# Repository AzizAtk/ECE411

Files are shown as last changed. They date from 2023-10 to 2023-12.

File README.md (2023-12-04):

# ECE411 Audio Visualizer

Team 5

Team Members: Abdulaziz Alateeqi, Meshal Almutairi, Gene Hu, Flynn Flynn

## Project Overview
This project is a dynamic audio visualizer that reacts to the audio input signal in real-time, by illuminating an LED panel in patterns and colors corresponding to the audio’s signal. This device will be a must-have gadget for tech enthusiasts to upgrade their listening space. By utilizing digital signal processing and Fast Fourier Transforms, audio signals are displayed visually as beautiful LED arrays. Just plug the device into a standard DC USB block and turn on the power switch and the device is ready to operate.

## System Architecture
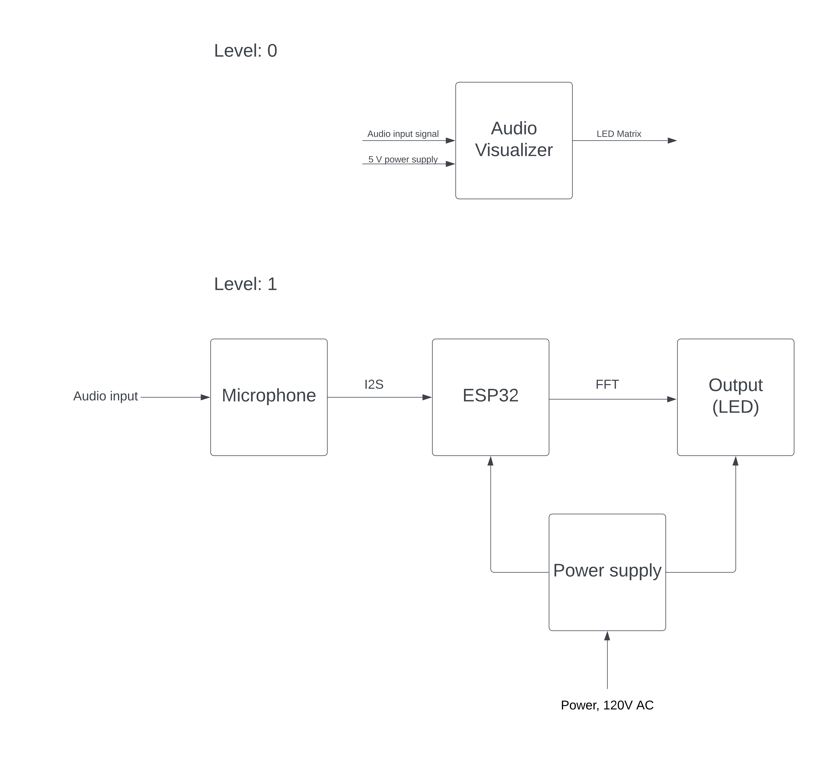
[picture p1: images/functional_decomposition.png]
func_decomp


## CAD Design
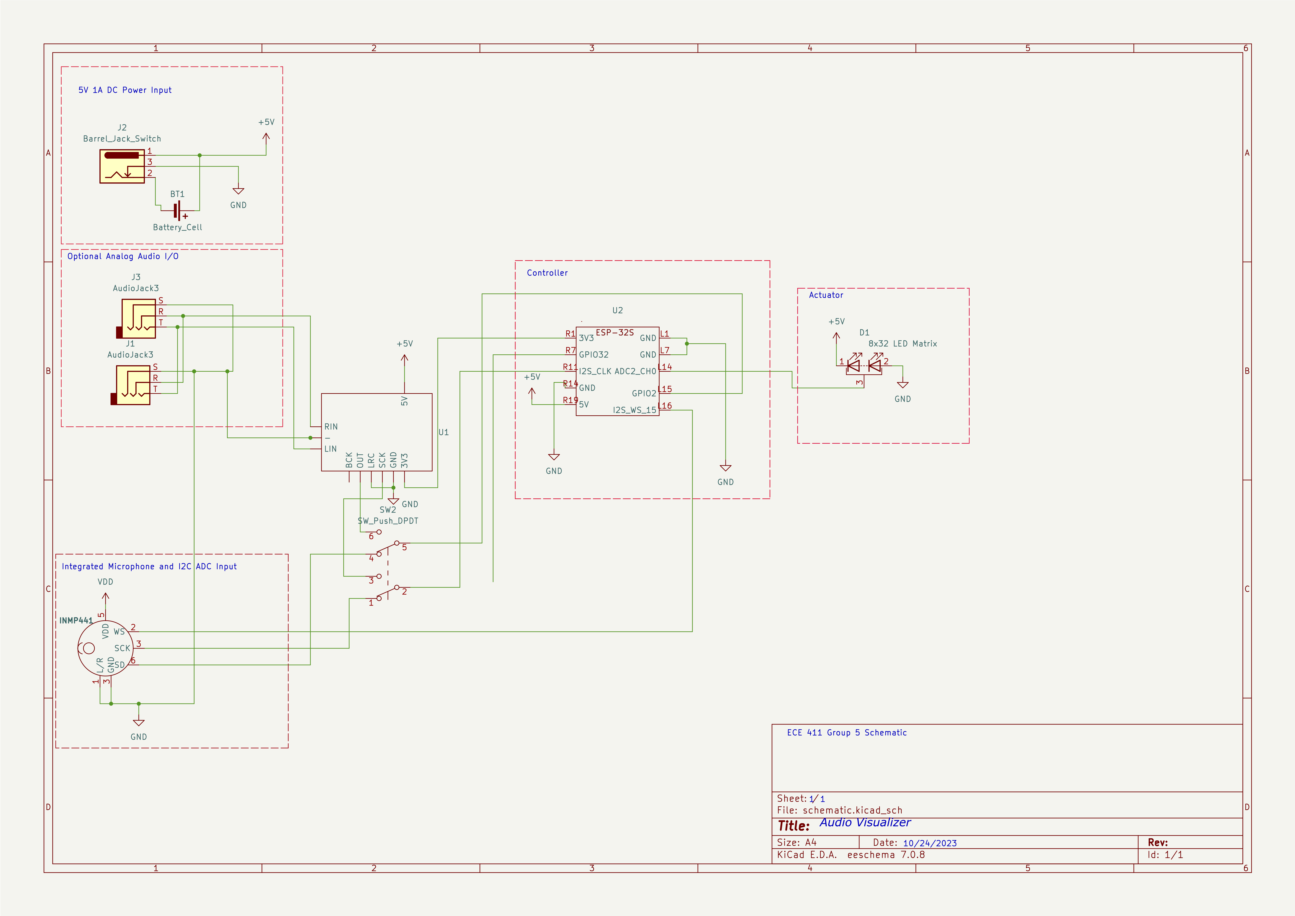
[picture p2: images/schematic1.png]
schematic1

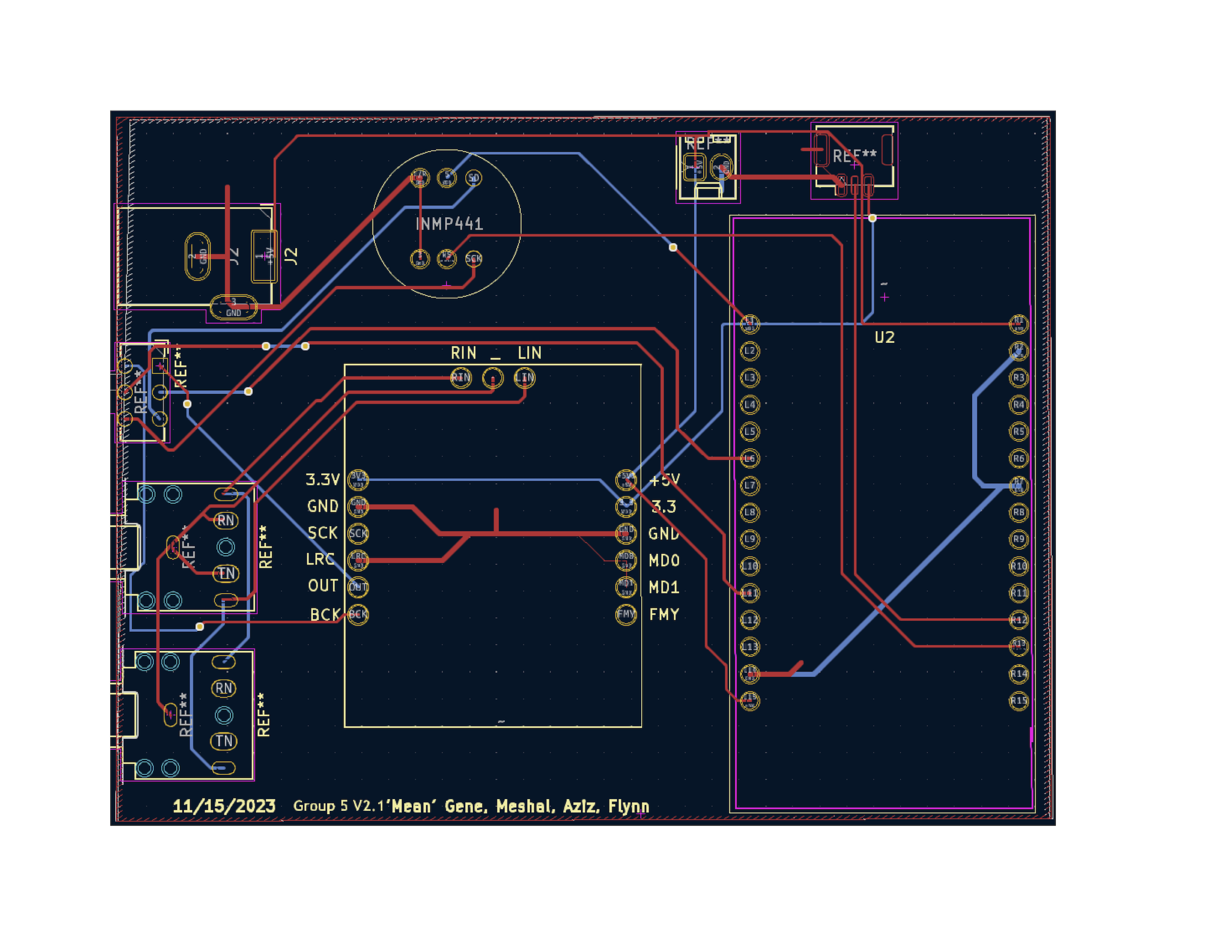
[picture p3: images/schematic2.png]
schematic2


## Software Design

### Audio
- The audio is sampled using I2S.

### FFT
- The FFT is implemented using the ArduinoFFT library.
- The FFT is used to convert the audio signal from the time domain to the frequency domain.
- The FFT is used to determine the amplitude of each frequency.

### LED Matrix
- The LED matrix is controlled using the FastLED and LEDMatrix libraries.
- The LED matrix is used to display the amplitude of each frequency as a bar graph.

## Prototype
<details>
  <summary>Click to expand prototype</summary>

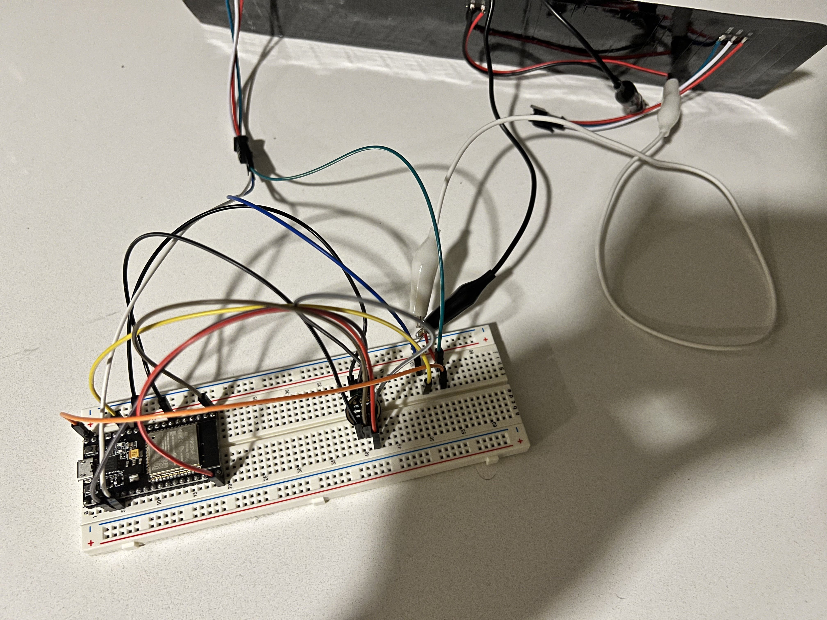
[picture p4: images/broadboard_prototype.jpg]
prototype
  
</details>

## Design Specification

### Power Requirements
The project will require dedicated 5V 3A power that will need a dedicated AC wall adapter.
- A 2.1mm barrel jack will be mounted directly to the board.
- A standard USB to 2.1mm cable will attach to a Samsung USB block.
- The 5V will attach to the board via a trace (larger duty).

### Sensors
- The first input will be switchable between a 3.5mm TRS line level input.
  - This will run directly to Ain and Din on the ESP32.
  - The input TRS 3.5mm jack will be wired directly to a second TRS that routes audio to an external powered speaker.
- INMP441 microphone module.
- Inputs will be switchable with only one operating at a time.

### Actuators
- The output of the device will be an 8x32 LED matrix.
- The display will be a two-dimensional spectrogram.
  - The X-axis is the different frequencies.
  - The Y-axis is amplitude in volts.
- This will be done by individually addressing each light using each frequency as a logic parameter and the voltage reading to determine how many lights from that column illuminate.
- This will be on a purchased breakout board with power, ground, and address/clk line being connected to PCB via a 4-pin ribbon cable.

### Processing
- All processing will be done on an ESP32 microcontroller.
- Arduino IDE will be used as the programming environment.
- The controller will take in digital audio signals and process them into the frequency domain as a Fourier Transform.
- Different frequencies will be made into control loops for the program output.
- ESP32 will be mounted to the PCB via headers and sockets so the microcontroller can be removed for programming.

## Requirements

### Performance
- Must continuously visualize the input sound until switched off.
- Must be displaying accurate information (i.e., high LED bar if the frequency is overwhelming).
- Must be able to use a microphone to process the audio of surroundings.
- Should be able to take in sound through an audio jack.
  - Should have a speaker.

### User Experience
- Must be portable.
- Must be wall-powered through the adapter.
- Should be simple to use (plug and go).
- May use batteries.
  - May be rechargeable.

### Safety
- Must not overheat or be at risk of burning out LEDs.
- May be able to withstand being dropped lightly (No shattering?).

### Miscellaneous
- Should be able to switch the audio rails for input/output instead of having two separate lines.

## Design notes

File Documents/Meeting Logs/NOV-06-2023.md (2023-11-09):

### Meeting Summary:
   1. Short meeting to create a BOM
      - Missing some part details that needs to be filled
   2. Worked on functional decomposition

### For Next Meeting:
    1. Must discuss how to split the frequency bands in higher detail
    2. Finish up BOM and functional decomposition before Thursday

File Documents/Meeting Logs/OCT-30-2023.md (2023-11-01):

### Meeting Summary:
   1. Created a comprehensive project schedule.

### For Next Meeting:
1. Revise schematic
2. Make Bill of Materials (BOM)
3. Draw top-level block diagrams (functional decomposition)
4. Work on sensors and actuators software

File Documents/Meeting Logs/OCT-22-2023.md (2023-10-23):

### Meeting Summary:
   1. Completed "HW Wk 05 - Make a decision!"
   2. The LED matrix and microphone has been received
   3. Flynn started working on a preliminary schematic
   4. Started keeping track of a bill of matrials
   5. Ordered three ESP32
   6. Decided on roles
      -   Flynn: Hardware
      -   Meshal: Head software developer
      -   Gene: Junior developer 
      -   Aziz: Junior developer 

### For Next Meeting:
1. Complete the preliminary schematic

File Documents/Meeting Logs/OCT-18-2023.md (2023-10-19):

### Meeting Summary:
   1. Completed PDS

### Parts list:
#### Parts we have:
- ESP32
- Switch
- Power Cable
##### Parts to order:
- [INMP441 Microphone](https://www.amazon.com/AITRIP-Omnidirectional-Microphone-Precision-Interface/dp/B092HWW4RS/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,aps,157)
- Headphone jack input module
- [8x32 LED Panel](https://www.amazon.com/dp/B088BTXHRG/?th=1)
- Speaker
- Diffusive filter panel

### For Next Meeting:
1. Order parts
2. Work on HW5
3. Look into 3D printing enclosure

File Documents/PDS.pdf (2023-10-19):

# Product Description Specification

### October 19, 2023

### ECE 411 Dr. Andrew Greenberg

### TEAM 5

Abdulaziz Alateeqi, | Meshal Almutairi
Flynn Flynn, | Gene Hu

## Executive Summary

The audio visualizer takes an audio input from the user and displays a visual representation of the processed audio signal on an LED panel. This device will be a must have gadget for tech enthusiasts to upgrade their listening space. By utilizing digital signal processing and fast fourier transforms, audio signals are displayed visually as beautiful LED arrays. Just plug the device into a standard DC USB block and turn on the power switch and the device is ready to operate.

## Market Analysis

Our audio visualizer is tailored for musicians and music listeners seeking to enhance their listening experience with visual flair. In the current market, the main competitor is software-based solutions that offer real-time music visualization on screens. Our product distinguishes itself by providing a seamlessly integrated audio-visual experience. Considering the cost of components and the product’s unique appeal, we expect the price to be around $40.

## Requirements

### Performance

1. Must continuously visualize the input sound until switched off
2. Must be displaying accurate information (i.e. high LED bar if the frequency is overwhelming)
3. Must be able to use a microphone to process audio of surrounding
4. Should be able to take in sound through an audio jack
a. Should have a speaker

### User Experience

1. Must be portable
2. Must be wall powered through adapter
3. Should be simple to use (plug and go)
4. May use batteries
a. May be rechargeable

1

### Safety

1. Must not overheat or be at risk of burning out LEDs
2. May be able to withstand being dropped lightly (No shattering?)

### Miscellaneous

1. Should be able to switch the audio rails for input/output instead of having two separate lines

## System Architecture

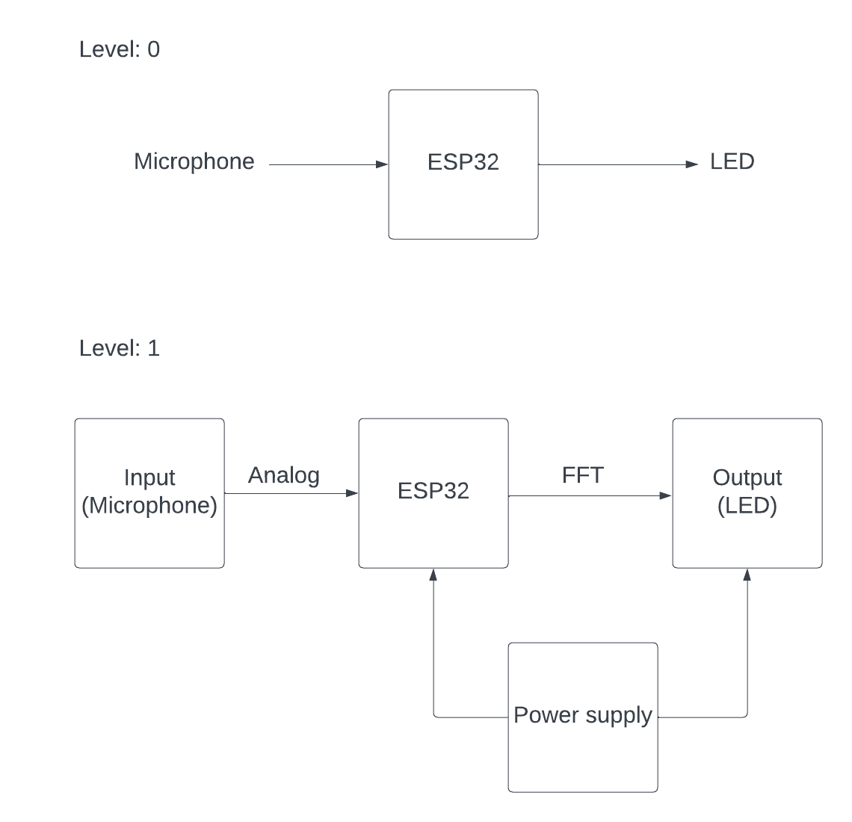
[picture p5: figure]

## Design Specification

### Power requirements

The project will require dedicated 5v 3A power that will need a dedicated AC wall adapter.

- A 2.1mm barrel jack will be mounted directly to the board

2

- A standard USB to 2.1mm cable will attach to a samsung USB block
- The 5v in will attach to the board via a trace (larger duty)

### Sensors

- First input will be switchable between a 3.5mm TRS line level input
- This will run directly to Ain and Din on the ESP32
- The input TRS 3.5mm jack will be wired directly to a second TRS that routes audio to an external powered speaker.
- INMP441 microphone module
- Inputs will be switchable with only one operating at a time

### Actuators

- The output of the device will be an 8x32 LED matrix.
- The display will be a two dimensional spectrogram.
- X-axis is the different frequencies.
- Y-axis is amplitude in volts.
- This will be done by individually addressing each light using each frequency as a logic parameter and the voltage reading to determine how many lights from that column illuminate.
- This will be on a purchased breakout board with pwr, gnd and address/clk line being connected to PCB via a 4 pin ribbon cable.

### Processing

- All processing will be done on a ESP32 microcontroller.
- Arduino IDE will be used as the programming environment.
- The controller will take in digital audio signals and process them into the frequency domain as a Fourier Transform.
- Different frequencies will be made into control loops for the program output.

3

- ESP32 will be mounted to the pcb via headers and sockets so the microcontroller can be removed for programming.

4

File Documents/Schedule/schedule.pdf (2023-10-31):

ece411 Project Schedule | Oct 30, 2023 http://

## Project manager

Project dates | Oct 30, 2023 - Dec 8, 2023
Completion | 0%
Tasks | 16
Resources | 4

Project schedule for ece411 team5's audio visualizer.

Name | Begin date | End date
Breadboard Prototype Create a breadboard prototype of the audio visualizer. Done by putting all the components together onto a BB and using wires on hand to connect the circuit. | 10/30/23 | 11/1/23

## Updated Schematic and Preliminary Layout

Your schematic should now be much closer to completion.

Your preliminary board layout should have all of your major components on it, including power supply, sensor, controller, and actuator. It should have a vaguely reasonable board outline. It doesn't have to be fully routed, or even halfway routed, but components should be grouped together, and components should be put in sane places.

And, of course, make sure this is checked in under version control!

Submit it in TWO WAYS:

Print a PDF of your schematic and board layout and upload it to Canvas. Enter a URL to your collaboration site to the folder where your schematic and layout files are checked in.

10/30/23 | 11/1/23

## Code Microphone

Interface microphone component with ESP32 and make it functional.

11/3/23 | 11/7/23

## Code LED Control

Interface 8x32 LED panel with ESP32 and be able to control it. Basic control being able to light up "bars" to represent the incoming frequencies.

11/3/23 | 11/7/23

## Code Frequency Analyzer

Code a frequency analyzer (FFS) onto the ESP32.

11/3/23 | 11/7/23

## Combine and Test Code

Combine the code from each component to get a working audio visualizer prototype.

11/8/23 | 11/12/23

## Debug and Fix

Debug the combined code and fix any errors.

11/13/23 | 11/17/23

## Bill of Materials

Final BOM filled here:
https://docs.google.com/spreadsheets/d/1jbas32DcEDZ59e13n7u7aIlfJYj-6RpcqCJsSKwKe8E/edit?usp=sharing

Make sure to upload to GitHub

11/4/23 | 11/5/23

## Rough Draft of CAD

The only things left are changes for out of stock components, changes from design reviews, changes for DFX, etc.!

And, of course, make sure this is checked in under version control!

Submit it in TWO WAYS:

Print a PDF of your schematic and board layout and upload it to Canvas. Enter a URL to your collaboration site to the folder where your schematic and layout files are checked in.

11/5/23 | 11/7/23

## Functional Decomposition

Draw a top-level (Level 0) block diagram of your practicum project showing all inputs and outputs.

Draw a Level 1 block diagram showing the principal components or modules of your project along with the interconnections between them. LABEL ALL INTERCONNECTIONS.

Consult the lecture slides for proper format for capturing the block diagram and describing inputs and outputs.

Post these to your collab site and upload a PDF to Canvas.

11/4/23 | 11/6/23

## Design Review

Have at least one other team design review your schematic and layout. Bonus points for more than one design review by more than one team. Be attentive! Take notes!

Submit which team(s) (use their team number) did your design review(s).

11/11/23 | 11/14/23
ece411 Project Schedule | Oct 30, 2023
Tasks | 2

Name | Begin date | End date
Final CAD After your design review, fix all of the critical issues, go through all the checklists again, and then declare it done! And of course, check it in to your versioning system! Submit it in TWO WAYS: Print a PDF of your schematic and board layout and upload it to Canvas. Enter a URL to your collaboration site to the folder where your schematic and layout files are checked i | 11/15/23 | 11/16/23

## Send Board to FAB

Must be sent between 12 p.m. Thursday and 10 a.m. Friday.

11/16/23 | 11/16/23

## Test Plan

Create a comprehensive hierarchical test plan for your practicum project. Consult the course lecture notes for guidelines. Submit at least three test plans (see optional testing template document).

Create detailed test case descriptions for two tests included in your test plan.

Your work will be graded on completeness, conformance to design documentation requirements as described in class, and quality and clarity of the individual test cases.

Post these to your team wiki and upload a single PDF file of them to Canvas.

11/23/23 | 11/27/23
Assemble Final Build | 11/28/23 | 11/28/23
Presentation 30 minutes, either Thursday or Friday | 12/7/23 | 12/7/23
Tasks | 3

Name | Default role
Gene Hu | developer
Flynn | developer
Meshal | developer
Aziz | developer

# Resources

# Gantt Chart

Name | Begin date | End date
Breadboard Prototype | 10/30/23 | 11/1/23
Updated Schematic and... | 10/30/23 | 11/1/23
Code Microphone | 11/3/23 | 11/7/23
Code LED Control | 11/3/23 | 11/7/23
Code Frequency Analyzer | 11/3/23 | 11/7/23
Combine and Test Code | 11/8/23 | 11/12/23
Debug and Fix | 11/13/23 | 11/17/23
Bill of Materials | 11/4/23 | 11/5/23
Rough Draft of CAD | 11/5/23 | 11/7/23
Functional Decomposition | 11/4/23 | 11/6/23
Design Review | 11/11/23 | 11/14/23
Final CAD | 11/15/23 | 11/16/23
Send Board to FAB | 11/16/23 | 11/16/23
Test Plan | 11/23/23 | 11/27/23
Assemble Final Build | 11/28/23 | 11/28/23
Presentation | 12/7/23 | 12/7/23
Oct'2023 | November 2023 | December 2023
30 | 31

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
9 | 10 | 11 | 12 | 13 | 14 | 15 | 16 | 17 | 18 | 19 | 20 | 21 | 22 | 23 | 24 | 25 | 26 | 27 | 28 | 29 | 30

1

2

3
4

Send Board to FAB

# Resources Chart

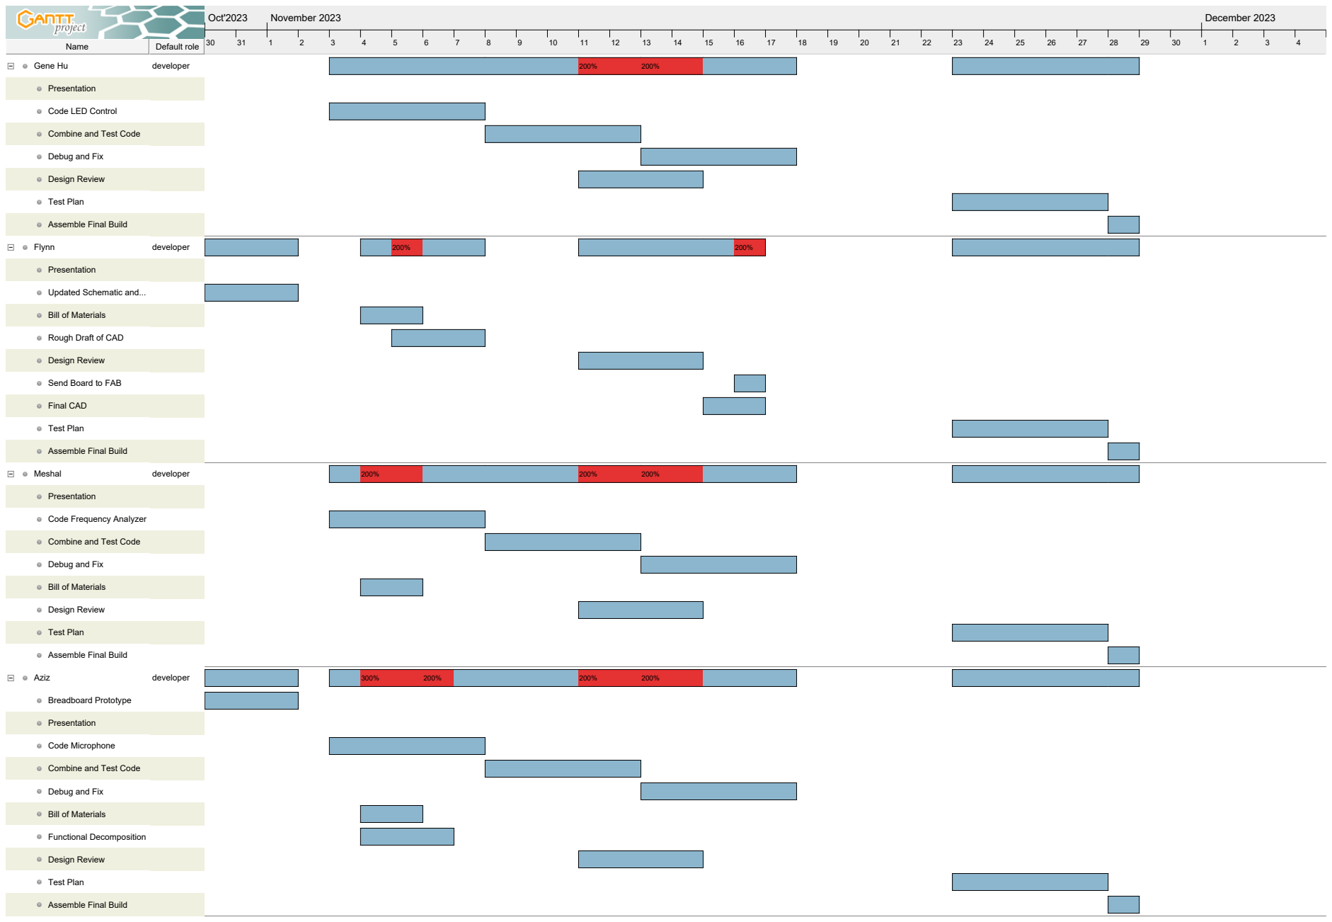
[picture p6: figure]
Name; Default role; Gene Hu; developer; Presentation; Code LED Control; Combine and Test Code; Debug and Fix; Design Review; Test Plan; Assemble Final Build; Flynn; Updated Schematic and...; Bill of Materials; Rough Draft of CAD; Send Board to FAB; Final CAD; Meshal; Code Frequency Analyzer; Aziz; Breadboard Prototype; Code Microphone; Functional Decomposition; Oct'2023; November 2023; December 2023

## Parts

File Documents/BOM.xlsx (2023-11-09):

Bill Of Materials for: Team 5
Last modified: 11/06/2023
PCB version: 0.1
BOM revision: 2 |  | P/NP | = Place/Not Place (components marked NP are not stuffed on the board)
Cnt | Part References | P/NP | Mfg | Mfg PN | Description | Dist | Dist Part Number | Cost Ea. | Cost Total
4 | C11, C17, C22, C23 | P | Yageo | CC0603KRX5R7BB105 | 1µF ±10% 16V Ceramic Capacitor X5R 0603 | Digi-Key | 311-1444-1-ND | $0.11 | $0.44
1 | D1 | P | BTF-LIGHTING | WS2812B ECO RGB | 8X32 programmable LED Matrix | Amazon | - | $18.99 | $18.99
5 | Mic1 | P | AITRIP | INMP441 | Omnidirectional Microphone Module | Amazon | - | $2.80 | $13.99
10 | J1 | NP | TRRS | 3.5mm Audio Jack Breakout Board | Connector_Audio:AudioJack3 | Amazon | - | $0.60 | $5.99
10 | J2 | P | DAYKIT | 12V Male+Female 2.1x5.5MM DC Power Jack | Connector:Barrel_Jack_Switch | Amazon | - | $0.80 | $7.99
1 | U1 | P | Texas Instruments | PCM1808PWR | CJMCU-1808 ADC converter | Digi-Key | 296-26307-6-ND | $1.81 | $1.81
3 | U2 | P | Espressif Systems | ESP32-DEVKITM-1 | ESP WROOM 32 microcontroller | Digi-Key | 1965-ESP32-DEVKITM-1-ND | $5.29 | $15.88
 |  |  |  |  |  |  |  | TOTAL: | $65.09
VERSION INFO
Rev | Date | Notes
0.1r1 | 2023-11-06 | Initial BOM. All parts chosen. Most are missing Dist Part Number.

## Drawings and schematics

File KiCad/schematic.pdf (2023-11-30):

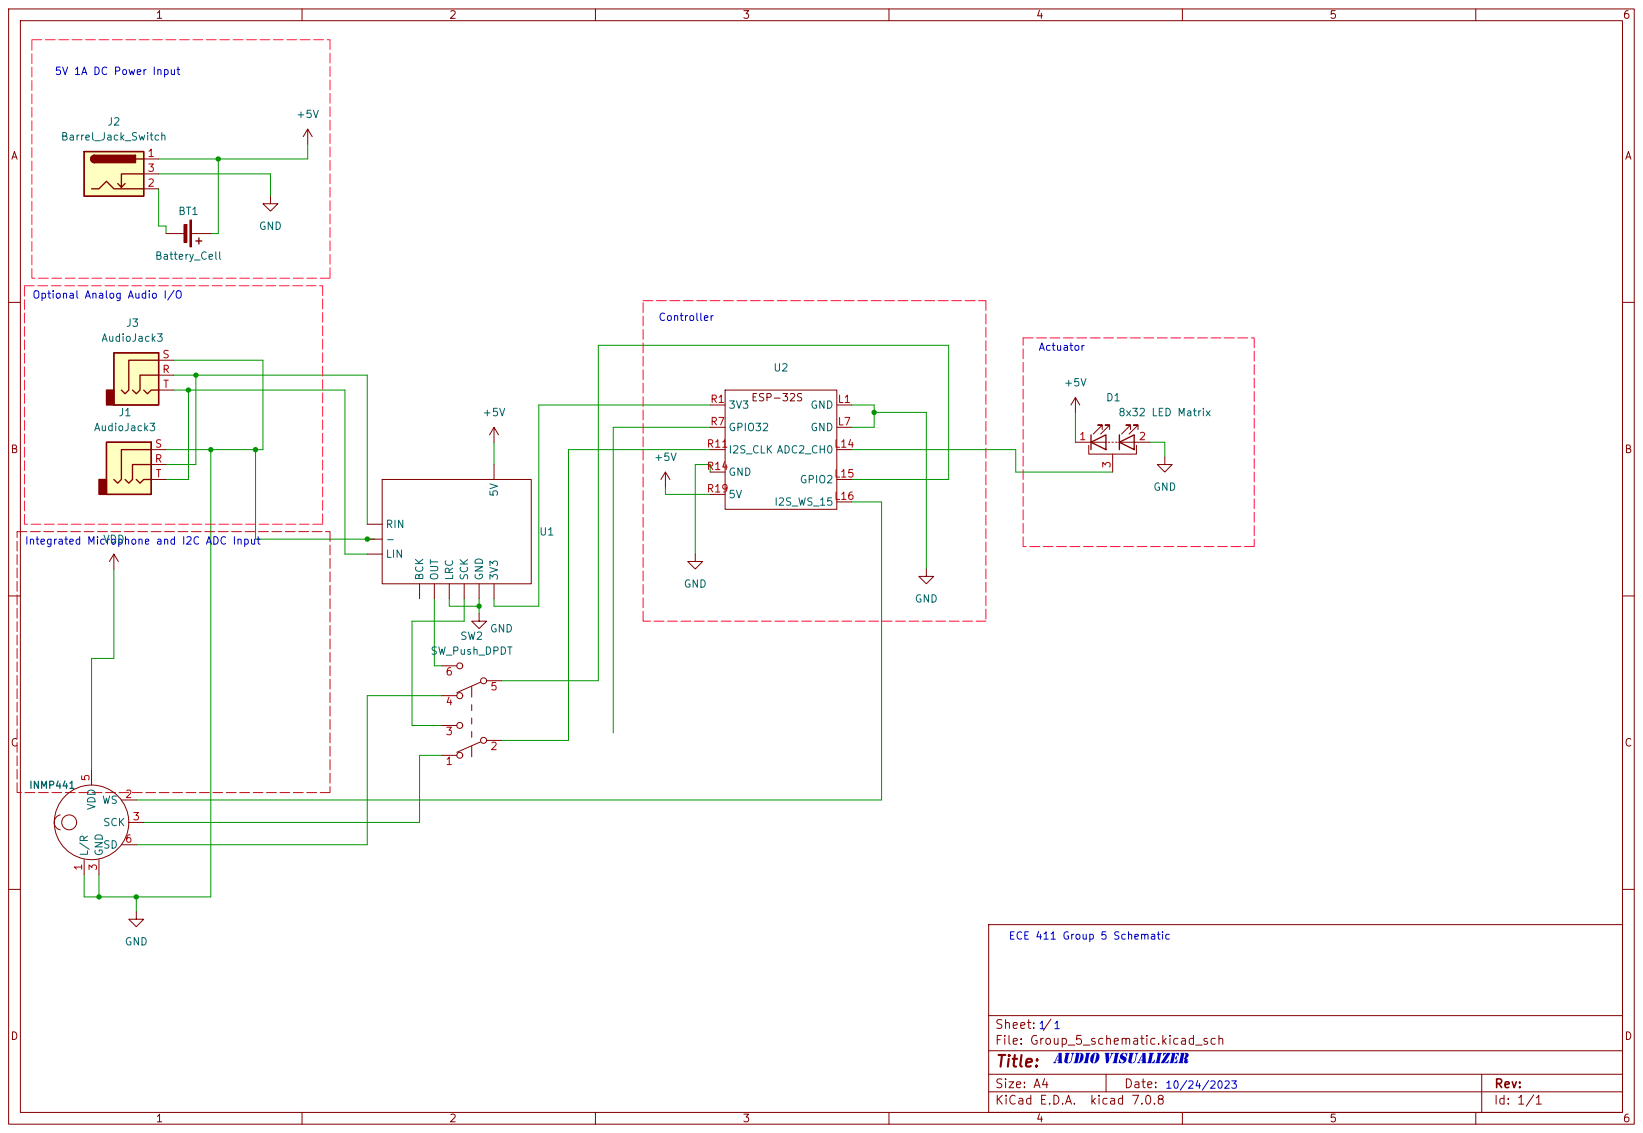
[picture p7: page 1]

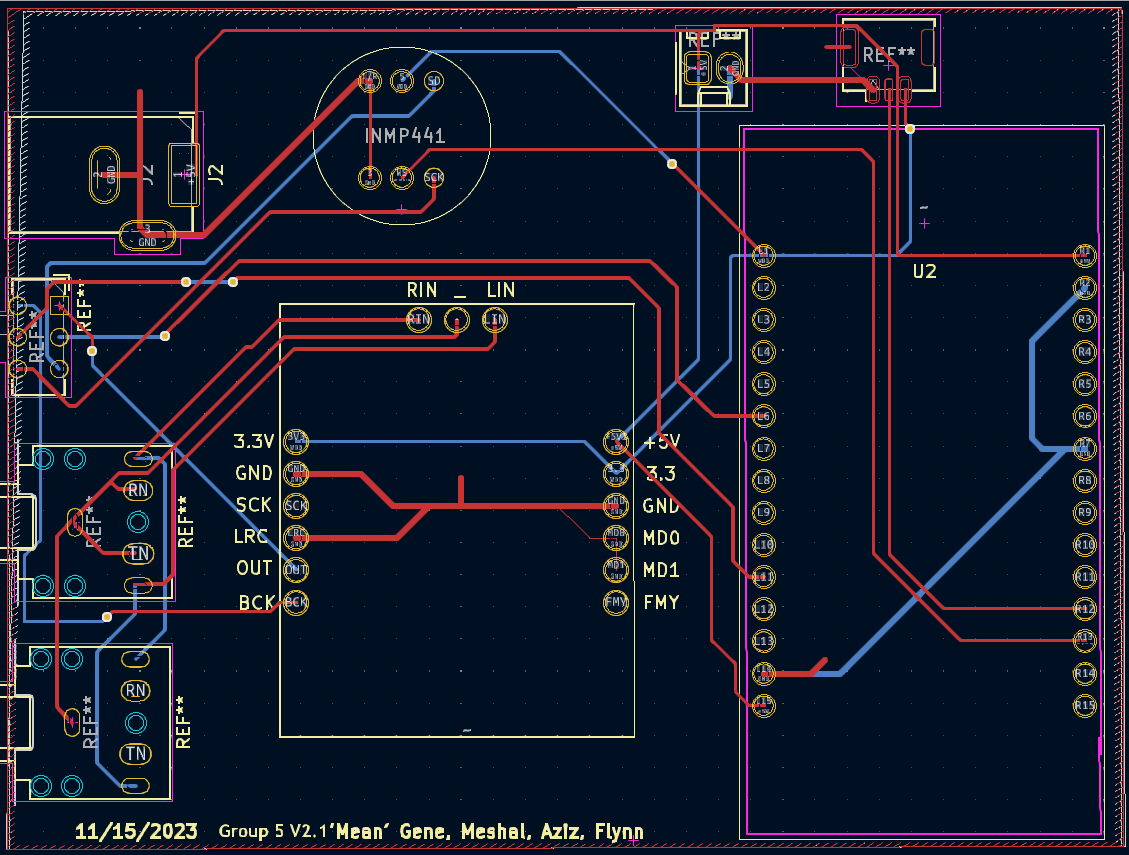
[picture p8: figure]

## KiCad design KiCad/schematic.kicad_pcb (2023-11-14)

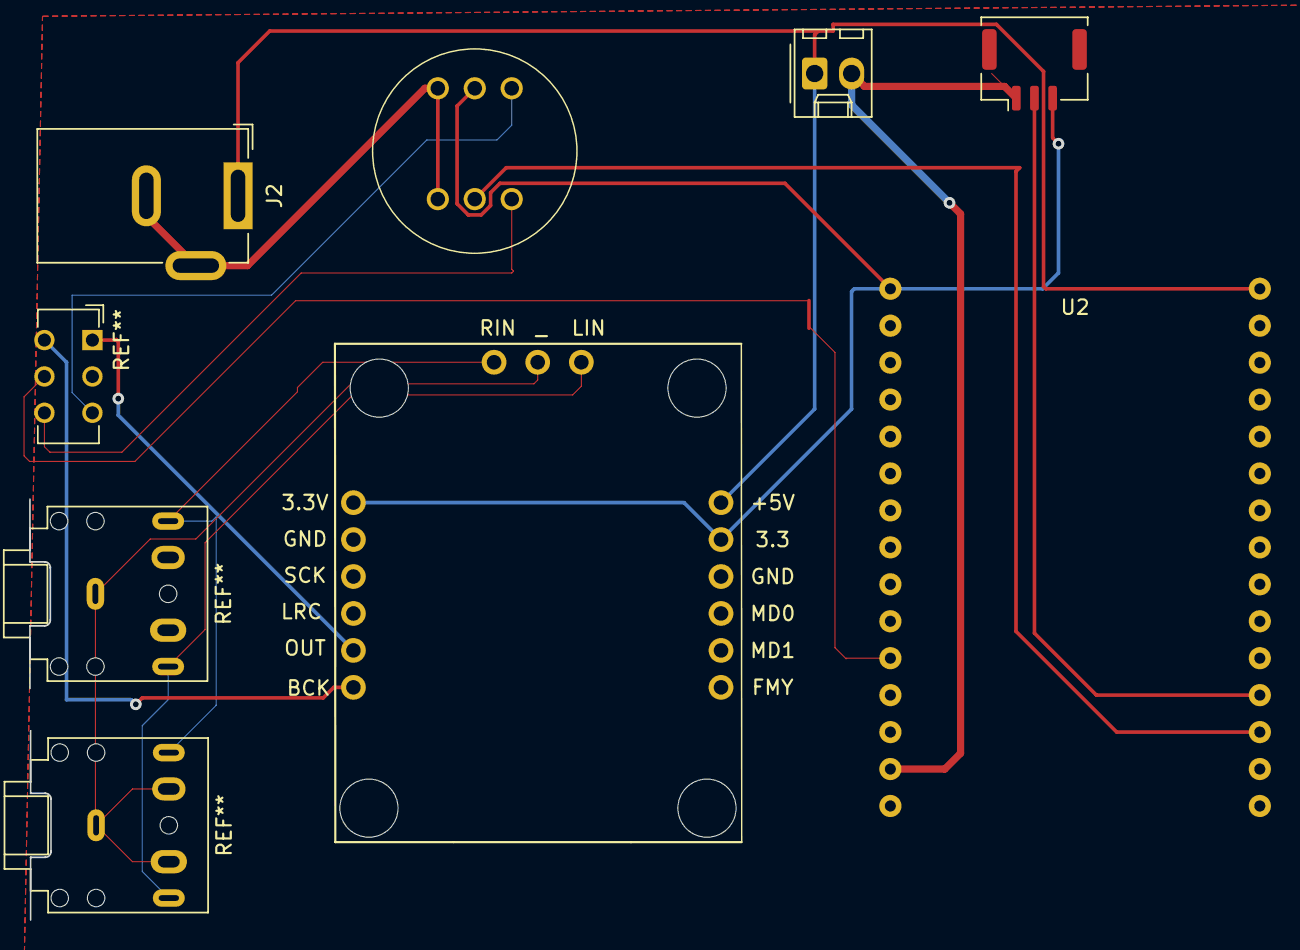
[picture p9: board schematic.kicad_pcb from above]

Board: 2 copper layers, 4 parts (0 on the bottom side), 4 nets.

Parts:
J2: Barrel_Jack_Switch; BarrelJack_GCT_DCJ200-10-A_Horizontal
Mic1: INMP441
U1: CJMCU_FT232H
U2: ESP32-DOIT-DEVKIT

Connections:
+5V: J2.1, U1.+5V1, U2.L15, U2.R1
GND: J2.2, J2.3, Mic1.3 (GND), Mic1.L/R (SD), U1.GND, U2.L14, U2.R2, U2.R7
unnamed: Mic1.WS, U2.R13
VDD: Mic1.5 (VDD), U1.3.3, U1.3V3, U2.L1

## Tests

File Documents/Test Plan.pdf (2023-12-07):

# Test Plan

December 6, 2023

ECE 411
Dr. Andrew Greenberg

TEAM 5
Abdulaziz Alateeqi, | Meshal Almutairi
Flynn Flynn, | Gene Hu

## Unit Tests:

- Test power supply provides 5 volts to the system.
- Test microphone, I2S protocol.
- Test each cell in the LED matrix and verify that each can be individually controlled by ESP32.

## Verification Tests:

- ESP32 is able to take in input from the microphone and output a corresponding display on the LED matrix (audio visualizer).
- Switch is able to sever connection between power supply and ESP32 (on PCB).
- Components all attached to PCB instead of a breadboard will still be able to work and have power supplied.

## Validation Tests:

- Displayed LEDs should be conveying accurately what kind of sounds it is taking in. The information are:
- Intense sound would fill a bar up
- High frequency noises will populate the right side of the matrix
- Low frequency noises will populate the left side of the matrix

Test Author: Gene
Test Case Name: | LED Matrix Interface | Test ID #: | 01
Description: | This test case will be testing the libraries LedMatrix and FastLED to interface with the LED matrix | Type: | □ white box

Tester Information
| Name of Tester: | Gene | Date: | 11/12/2023
| HW/SW Version: | 1.0 | Time: | N/A
| Setup: | The LED matrix needs to be connected to an ESP32 through breadboard or wires, and an appropriate IDE is required to be able to download libraries and upload code to the microcontroller.
S T E P | Action | Expected Result | P A S S | F A I L | N / A | Comments
1 | Turn on LED (0,0) as red | Bottom right LED is red | x | | | Make sure delays are adequate so these steps can be seen.
2 | Turn on LED (0,7) as blue | Top right LED is blue | x
3 | Turn on LED (31,0) as yellow | Bottom left LED is yellow | x
4 | Turn on LED (31,7) as green | Top left LED is green | x
5 | Turn on all LEDs as red | Entire board lights up to red | x
6 | Turn on all LEDs as yellow | Entire board lights up to yellow | x
7 | Turn on all LEDs as green | Entire board lights up to green | x
8 | Vary the brightness from low to high (0 to 127) | Board ramps up from 0 bright brightness to 50% brightness | x | | | 50% brightness is VERY bright.
9 | Turn off LEDs one by one starting from (0,0) to (31,7) | LEDs start turning off starting from bottom to top, right to left | x
| Overall test result: | | x

Test Author: Aziz
Test Case Name: | Basic microphone functionality | Test ID #: | 02
Description: | This test case will be I2S protocol and assures that the microphone works | Type: | □ white box

Tester Information
| Name of Tester: | Aziz | Date: | 11/15/2023
| HW/SW Version: | 1.0 | Time: | N/A
| Setup: | The microphone needs to be connected to an ESP32 through breadboard or wires, and an appropriate IDE is required to be able to download libraries and upload code to the microcontroller.
S T E P | Action | Expected Result | P A S S | F A I L | N / A | Comments
1 | Configure pins for I2S | ESP32 recognizes the microphone | x
2 | Make any sort of noise | Should print the input frequency | x
3 | Play 20 kHz sound | Should display the frequency | x
4 | Try to be in a quiet environment | Should display noise | x
| Overall test result: | | x

Test Author: Meshal

Test Case Name: | Audio Visualizer Program | Test ID #: | 03
Description: | This test case will be connecting the microphone and LED matrix programs together such that sound data coming from the microphone will be visualized on the LED matrix in the form of colored bars. The bar height will be based on the intensity of the frequencies. | Type: | □ white box

Tester Information

| Name of Tester: | Meshal | Date: | 11/17/2023
| HW/SW Version: | 1.0 | Time: | N/A
| Setup: | The microphone, LED matrix, and ESP32 need to be connected together on a breadboard. An IDE that can download and use .ino libraries to interface with microphone and LED matrix..
T E S T | INPUTS | EXPECTED OUTPUTS | P A S S | F A I L | N / A | Comments
1 | Loud sound | Bar heights will be near or at max height. | x
2 | Quiet sound | Bar heights will be near or at the lowest height. | x | | | Microphone is pretty sensitive. All bars have the lowest LED on due to background noise.

3 | High frequency sounds | The population of lit LEDs should be towards the right. | x
4 | Low frequency sounds | The population of the lit LEDs should be towards the left. | x
5 | Middling frequency sounds | The population of the lit LEDs should be in the middle. | x
6 | Varying volume of the sound | The bars should rise up as the volume gets louder. | x
| Overall test result: | | x

Test Author: Flynn

Test Case Name: | Power is Being Supplied | Test ID #: | 04
Description: | This test case will be testing if the PCB is distributing power correctly. If working, the ESP32, microphone, and LED matrix will be powered on when the power supply is plugged in. | Type: | □Gray box

Tester Information

| Name of Tester: | Flynn | Date: | 11/28/2023
| HW/SW Version: | 1.0 | Time: | 5:00 pm
| Setup: | PCB with all components attached.
T E S T | INPUTS | EXPECTED OUTPUTS | P A S S | F A I L | N / A | Comments
1 | Voltage from the power supply is plugged into the power terminal. | ESP32 turns on, LED matrix lights up, and microphone is giving data to ESP32. | o | x | | GND pin of jack not connected. Jumper was connected to battery tab and ESP boots up
2 | +3V VDD supply powering I2S microphone and ADC board | Microphone is able to be detected when connecting via PCB to Arduino program | x
3 | +5V rail to power LED Matrix | LED Matrix should show bottom row of light illuminate when power attached | x
| Overall test result: | | x

Test Author: Flynn
Test Case Name: | Product Functionality | Test ID #: | 05
Description: | This will test the general operations of the device to take in inputs, process the audio and output the audio spectrum on the LED matrix in real time. | Type: | □ white box

Tester Information
Name of Tester: | Gene, Aziz, Meshal, Flynn | Date: | 11/28/23
HW/SW Version: | 1.0 | Time: | 6:00 pm
Setup: | PCB fully populated with external power to board and
T E S T | INPUTS | EXPECTED OUTPUTS | P A S S | F A I L | N / A | Comments
1 | I2S Microphone. | LED matrix displays FFT of room audio in real time. | o | x | | Routing of ESP32 and board found mismatched. Changes to code and pin-pin jumpers resolved issues.
2 | 3.5mm analog audio (Additional feature) | LED matrix displays FFT of aux cable audio in real time. | | x | | PCB routing for ADC mirrored. ADC will need to be desoldered, rotated, and retested.
3 | Switching between inputs | LED matrix changes which input it is displaying from | | | x | Since Analog is not working, all that can be tested is that the input changes.
| Overall test result:

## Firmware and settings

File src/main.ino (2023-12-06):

/**
 * @file    main.ino
 * @author  ECE411 Team 5:
 *            Abdulaziz Alateeqi,
 *            Meshal Almutairi,
 *            Flynn Flynn,
 *            Gene Hu.
 * @brief   Audio Visualizer source code.
 *
 * @copyright Copyright (c) 2023
 *
 */

#include <Arduino.h>
#include <FastLED.h>
#include <LEDMatrix.h>
#include "audio_reactive.h"

#define BRIGHTNESS 32  // Set the brightness level (0-255)
#define LED_PIN 26
#define MATRIX_WIDTH 32
#define MATRIX_HEIGHT 8
#define BANDS 16
#define BAR_WIDTH 2
#define NUM_LEDS (MATRIX_WIDTH * MATRIX_HEIGHT)

cLEDMatrix<MATRIX_WIDTH, MATRIX_HEIGHT, VERTICAL_ZIGZAG_MATRIX> led_matrix;

typedef struct {
  int x;
  int y;
} Coordinate;

int fft_results[16];  // Results from FFT
uint8_t previous_fft_values[16] = {};
uint8_t bar_heights[16] = {};
uint8_t peaks[16] = {};
uint64_t color_shift = 0;

void setup() {
  Serial.begin(115200);

  setup_audio();
  FastLED.addLeds<WS2812B, LED_PIN, GRB>(led_matrix[0], NUM_LEDS);
  FastLED.setBrightness(BRIGHTNESS);
  draw_start_screen();
}

void loop() {
  fadeToBlackBy(led_matrix[0], NUM_LEDS, 32);

  // Process FFT results
  for (int i = 0; i < BANDS; i++) {
    uint8_t fft_value = fft_results[i];
    fft_value = ((previous_fft_values[i] * 3) + fft_value) / 4;  // Smooth
    bar_heights[i] = fft_value / (255 / MATRIX_HEIGHT);          // Scale bar height
    previous_fft_values[i] = fft_value;

    if (bar_heights[i] > peaks[i]) {
      peaks[i] = min((int)bar_heights[i], MATRIX_HEIGHT - 1);
    }
  }

  // Draw bars
  for (int band = 0; band < BANDS; band++) {
    draw_bar(band, bar_heights[band]);
  }

  // Decay peaks
  EVERY_N_MILLISECONDS(200) {
    for (int i = 0; i < BANDS; i++) {
      if (peaks[i] > 0) {
        peaks[i]--;
      }
    }
  }

  // Shift colors over time
  EVERY_N_MILLISECONDS(250) {
    color_shift++;
  }

  FastLED.show();
}

/**
 * @brief Draw a bar on the LED matrix.
 *
 * @param band    Band number.
 * @param height  Bar height.
 */
void draw_bar(int band, int height) {
  int x_start = BAR_WIDTH * band;
  int y_max = MATRIX_HEIGHT - 1;

  for (int x = x_start; x < x_start + BAR_WIDTH; x++) {
    CHSV color = CHSV(band * 16 + color_shift, 255, 255);

    for (int y = 0; y <= height; y++) {
      led_matrix(x, y_max - y) = color;
    }

    // Draw peak
    if (peaks[band] > 0) {
      color.s /= 2.5;  // Desaturate
      led_matrix(x, y_max - peaks[band]) = color;
    }
  }
}

/**
 * @brief Draw the start screen.
 */
void draw_start_screen() {
  Coordinate ece411[] = {{2, 1},  {3, 1},  {4, 1},  {5, 1},  {8, 1},  {9, 1},  {12, 1}, {13, 1}, {14, 1}, {15, 1}, {20, 1}, {24, 1}, {28, 1},
                         {2, 2},  {7, 2},  {10, 2}, {12, 2}, {19, 2}, {20, 2}, {23, 2}, {24, 2}, {27, 2}, {28, 2}, {2, 3},  {3, 3},  {4, 3},
                         {7, 3},  {12, 3}, {13, 3}, {14, 3}, {18, 3}, {20, 3}, {24, 3}, {28, 3}, {2, 4},  {7, 4},  {10, 4}, {12, 4}, {18, 4},
                         {19, 4}, {20, 4}, {21, 4}, {24, 4}, {28, 4}, {2, 5},  {3, 5},  {4, 5},  {5, 5},  {8, 5},  {9, 5},  {12, 5}, {13, 5},
                         {14, 5}, {15, 5}, {20, 5}, {23, 5}, {24, 5}, {25, 5}, {27, 5}, {28, 5}, {29, 5}};
  int ece411_size = sizeof(ece411) / sizeof(ece411[0]);

  Coordinate team5[] = {
      {2, 1},  {3, 1},  {4, 1},  {5, 1},  {6, 1},  {8, 1},  {9, 1},  {10, 1}, {11, 1}, {14, 1}, {15, 1}, {18, 1}, {22, 1}, {26, 1}, {27, 1},
      {28, 1}, {29, 1}, {4, 2},  {8, 2},  {13, 2}, {16, 2}, {18, 2}, {19, 2}, {21, 2}, {22, 2}, {26, 2}, {4, 3},  {8, 3},  {9, 3},  {10, 3},
      {13, 3}, {14, 3}, {15, 3}, {16, 3}, {18, 3}, {20, 3}, {22, 3}, {26, 3}, {27, 3}, {28, 3}, {4, 4},  {8, 4},  {13, 4}, {16, 4}, {18, 4},
      {22, 4}, {29, 4}, {4, 5},  {8, 5},  {9, 5},  {10, 5}, {11, 5}, {13, 5}, {16, 5}, {18, 5}, {22, 5}, {26, 5}, {27, 5}, {28, 5},
  };
  int team5_size = sizeof(team5) / sizeof(team5[0]);

  FastLED.clear(true);
  delay(500);
  FastLED.showColor(CRGB::Red);
  delay(500);
  FastLED.showColor(CRGB::Green);
  delay(500);
  FastLED.showColor(CRGB::Blue);
  delay(500);
  FastLED.showColor(CRGB::White);
  delay(500);

  // Draw 'ECE 411'
  fill_solid(led_matrix[0], NUM_LEDS, CRGB(32, 0, 0));
  for (int i = 0; i < ece411_size; i++) {
    led_matrix(ece411[i].x, ece411[i].y) = CRGB::White;
  }
  led_matrix.DrawLine(0, 7, 31, 7, CRGB::Black);
  FastLED.show();
  delay(2000);

  FastLED.clear(true);
  delay(250);

  // Draw 'Team 5'
  fill_solid(led_matrix[0], NUM_LEDS, CRGB(32, 0, 0));
  for (int i = 0; i < team5_size; i++) {
    led_matrix(team5[i].x, team5[i].y) = CRGB::White;
  }
  led_matrix.DrawLine(0, 7, 31, 7, CRGB::Black);
  FastLED.show();

  delay(2000);
  FastLED.clear(true);
  delay(500);
}

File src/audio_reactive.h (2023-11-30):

/**
 * @file  audio_reactive.h
 * @brief Setup I2S and FFT to get audio data from the digital microphone and
 *       process it.
 *
 * @note  Based on WLED by atuline: https://github.com/atuline/WLED.
 *        FFT task is pinned to core 0.
 *
 */

#ifndef AUDIO_REACTIVE_H
#define AUDIO_REACTIVE_H

#include <arduinoFFT.h>
#include <driver/i2s.h>

// Audio configuration
#define GAIN 15    // Gain, boosts input level
#define SQUELCH 5  // Squelch, cuts out low level sounds

// I2S configuration
#define I2S_WS_PIN 13
#define I2S_SD_PIN 16
#define I2S_SCK_PIN 4
#define I2S_PORT I2S_NUM_0
#define MIN_SHOW_DELAY 15

// FFT configuration
const int block_size = 64;
const int sample_rate = 10240;
const uint16_t num_samples = 512;  // Must be a power of 2

TaskHandle_t fft_task_handle;

// FFT related variables
double major_peak = 0;
double magnitude = 0;
uint16_t raw_mic_data;  // Raw mic data

unsigned int sampling_period_us;
unsigned long microseconds;

// FFT arrays
extern int fft_results[16];  // Stores the final result
double real_values[num_samples];
double imag_values[num_samples];
double fft_bins[num_samples];
double fft_calculations[16];
double fft_result_max[16];

// Noise adjustment arrays
int linear_noise[16] = {34, 28, 26, 25, 20, 12, 9, 6, 4, 4, 3, 2, 2, 2, 2, 2};
double pink_noise_adjust[16] = {1.70, 1.71, 1.73, 1.78, 1.68, 1.56, 1.55, 1.63,
                                1.79, 1.62, 1.80, 2.06, 2.47, 3.35, 6.83, 9.55};

arduinoFFT FFT = arduinoFFT(real_values, imag_values, num_samples, sample_rate);

// Function prototypes
void setup_audio();
void i2s_install();
void i2s_setpin();
void test_microphone();
void read_microphone_data();
void execute_fft();
void post_process_fft();
double sum_fft_bins(int start, int end);
void fft_task(void* parameter);

void setup_audio() {
  i2s_install();
  i2s_setpin();
  delay(100);
  test_microphone();

  // Set sampling frequency
  sampling_period_us = round(1000000 * (1.0 / sample_rate));

  // Define the FFT Task and pin it to core 0
  xTaskCreatePinnedToCore(fft_task,          // Task function
                          "FFT Task",        // Task name
                          10000,             // Stack size in words
                          NULL,              // Task input parameter
                          1,                 // Task priority
                          &fft_task_handle,  // Task handle
                          0                  // Task core
  );
}

void i2s_install() {
  esp_err_t err;

  const i2s_config_t i2s_config = {
      .mode = i2s_mode_t(I2S_MODE_MASTER | I2S_MODE_RX),  // Receive mode
      .sample_rate = sample_rate * 2,  // Double the sample rate
      .bits_per_sample = i2s_bits_per_sample_t(16),
      .channel_format = I2S_CHANNEL_FMT_ONLY_LEFT,
      .communication_format = i2s_comm_format_t(I2S_COMM_FORMAT_STAND_I2S),
      .intr_alloc_flags = ESP_INTR_FLAG_LEVEL1,  // Interrupt level 1
      .dma_buf_count = 8,
      .dma_buf_len = block_size,
      .use_apll = false};

  err = i2s_driver_install(I2S_PORT, &i2s_config, 0, NULL);
  if (err != ESP_OK) {
    Serial.printf("Failed installing driver: %d\n", err);
    exit(1);
  }

  Serial.println("I2S driver installed.");
}

void i2s_setpin() {
  esp_err_t err;

  const i2s_pin_config_t pin_config = {.bck_io_num = I2S_SCK_PIN,
                                       .ws_io_num = I2S_WS_PIN,
                                       .data_out_num = -1,  // Not used
                                       .data_in_num = I2S_SD_PIN};

  err = i2s_set_pin(I2S_PORT, &pin_config);
  if (err != ESP_OK) {
    Serial.printf("Failed setting pin: %d\n", err);
    exit(1);
  }

  Serial.println("I2S pins configured.");
}

void test_microphone() {
  float mean = 0.0;
  int32_t sample_buffer[block_size];
  size_t bytes_read = 0;

  esp_err_t result = i2s_read(I2S_PORT, &sample_buffer, block_size, &bytes_read,
                              portMAX_DELAY);

  int samples_read = bytes_read / sizeof(int32_t);
  if (samples_read > 0) {
    for (int i = 0; i < samples_read; ++i) {
      mean += sample_buffer[i];
    }
    mean = mean / samples_read / 16384;
    Serial.println(mean != 0.0 ? "Digital microphone is working"
                               : "Digital microphone is not working");
  }
}

void read_microphone_data() {
  delay(1);
  microseconds = micros();

  for (int i = 0; i < num_samples; i++) {
    int32_t digital_sample = 0;
    size_t bytes_read = 0;
    esp_err_t result = i2s_read(I2S_PORT, &digital_sample,
                                sizeof(digital_sample), &bytes_read, 10);
    if (bytes_read > 0) {
      raw_mic_data = abs(digital_sample >> 16);
    }

    real_values[i] = raw_mic_data;
    imag_values[i] = 0;
    microseconds += sampling_period_us;
  }
}

void execute_fft() {
  FFT.Windowing(FFT_WIN_TYP_HAMMING, FFT_FORWARD);  // Weigh data
  FFT.Compute(FFT_FORWARD);                         // Compute FFT
  FFT.ComplexToMagnitude();                         // Compute magnitudes

  FFT.MajorPeak(&major_peak, &magnitude);  // Find most dominant frequency

  for (int i = 0; i < num_samples; i++) {
    double temp = abs(real_values[i]);
    temp /= 16.0;  // Reduce magnitude for linear scaling
    fft_bins[i] = temp;
  }
}

void post_process_fft() {
  // Define the bin ranges for each segment
  const int bin_ranges[16][2] = {
      {3, 4},      // 60 - 100 Hz
      {4, 5},      // 80 - 120 Hz
      {5, 7},      // 100 - 160 Hz
      {7, 9},      // 140 - 200 Hz
      {9, 12},     // 180 - 260 Hz
      {12, 16},    // 240 - 340 Hz
      {16, 21},    // 320 - 440 Hz
      {21, 28},    // 420 - 600 Hz
      {29, 37},    // 580 - 760 Hz
      {37, 48},    // 740 - 980 Hz
      {48, 64},    // 960 - 1300 Hz
      {64, 84},    // 1280 - 1700 Hz
      {84, 111},   // 1680 - 2240 Hz
      {111, 147},  // 2220 - 2960 Hz
      {147, 194},  // 2940 - 3900 Hz
      {194, 255}   // 3880 - 5120 Hz
  };
  const int divisors[16] = {2,  2,  3,  3,  4,  5,  6,  8,
                            10, 12, 17, 21, 28, 37, 48, 62};

  // Process each frequency range
  for (int i = 0; i < 16; i++) {
    fft_calculations[i] =
        sum_fft_bins(bin_ranges[i][0], bin_ranges[i][1]) / divisors[i];
    fft_calculations[i] =
        max(fft_calculations[i] - (float)SQUELCH * (float)linear_noise[i] / 4.0,
            0.0);
    fft_calculations[i] *= pink_noise_adjust[i];  // Adjust for pink noise
    fft_calculations[i] =
        fft_calculations[i] * GAIN / 40 + fft_calculations[i] / 16.0;
    fft_results[i] = constrain((int)fft_calculations[i], 0, 254);
  }
}

double sum_fft_bins(int start, int end) {
  double sum = 0.0;
  for (int i = start; i <= end; i++) {
    sum += fft_bins[i];
  }
  return sum;
}

void fft_task(void* parameter) {
  for (;;) {
    read_microphone_data();
    execute_fft();
    post_process_fft();
  }
}

#endif  // AUDIO_REACTIVE_H

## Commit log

2023-10-26 added KiCad folder
    [Group_5_schematic.kicad_sch]
2023-10-26 updated files
    [Group_5_schematic.kicad_sch]
2023-11-01 add oct 30 meeting log, broadbaord prototype
    [schematic.kicad_sch]
2023-11-03 update CAD
    [schematic.kicad_pcb, schematic.kicad_sch]
2023-11-09 add BOM
    [BOM.xlsx]
2023-11-11 add mic and LED matrix tests
2023-11-30 update schematic pdf to final version
